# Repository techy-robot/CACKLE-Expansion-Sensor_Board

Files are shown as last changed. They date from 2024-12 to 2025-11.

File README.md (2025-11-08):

---
modified: 2025-11-07T22:07:23-07:00
---
# Sensor Board

> [!TIP]
> This board is part of a larger modular control board ecosystem, [CACKLE](https://github.com/techy-robot/CACKLE)

This is a connector breakout board for vertical mezzanine connectors on a hub. It has one Qwiic connector, two nanoSPI connectors, and header breakouts for the free pins, chip select pins, and the SPI pins. Essentially it breaks out every pin accessible via the mezzanine connector.

Note that this does not fit the hubs by default because it sticks into the hub chaining headers. You will need a Vertical Spacer, or use the [2 connector sensor breakout](../2%20connector%20Sensor%20Board/README.md) instead, which does fit.

Schematic PDF

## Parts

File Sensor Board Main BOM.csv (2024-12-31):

Id | Designator | Footprint | Quantity | Designation | Supplier and ref
1 | J1 | PinHeader_1x05_P1.27mm_Vertical | 1 | SPI
2 | J7 | JST_SH_SM04B-SRSS-TB_1x04-1MP_P1.00mm_Horizontal | 1 | JST SH
3 | J3 | PinHeader_1x03_P1.27mm_Vertical | 1 | free pins
4 | J2,J5 | fpc_7pin_0.3mm_connector Panasonic | 2 | 7 pin FPC 0.3mm Panasonic Y3b
5 | R2,R4 | R_0603_1608Metric | 2 | 10k
6 | J15 | TE_mezzanine_conn_3-2363962-0 | 1 | TE 3-2363962-0 Connector

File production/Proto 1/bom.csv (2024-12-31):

Designator | Footprint | Quantity | Value | LCSC Part #
J15 | TE_mezzanine_conn_3-2363962-0 | 1 | TE 3-2363962-0 Connector | C425104
J2, J5 | fpc_7pin_0.3mm_connector Panasonic | 2 | 7 pin FPC 0.3mm Panasonic Y3b
J7 | JST_SH_SM04B-SRSS-TB_1x04-1MP_P1.00mm_Horizontal | 1 | JST SH
R2, R4 | 0603 | 2 | 10k | C25804

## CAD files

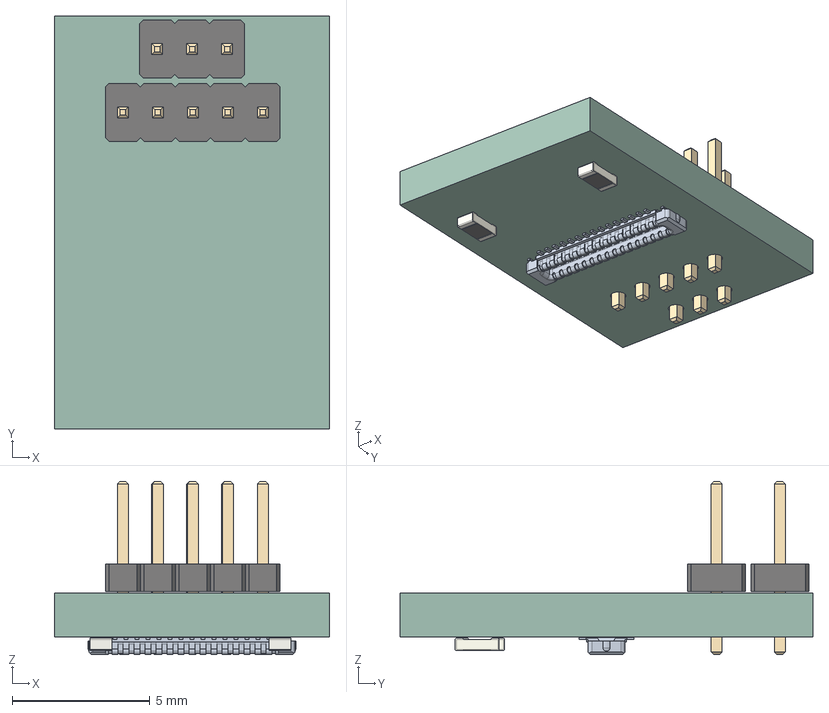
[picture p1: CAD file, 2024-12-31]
Sensor Board.step
10.0 x 15.0 x 6.30 mm
PinHeader_1x05_P127mm_Vertical
PinHeader_1x03_P127mm_Vertical
R_0603_1608Metric x 2
C-3-2363962-0
_autosave-Sensor Board_PCB

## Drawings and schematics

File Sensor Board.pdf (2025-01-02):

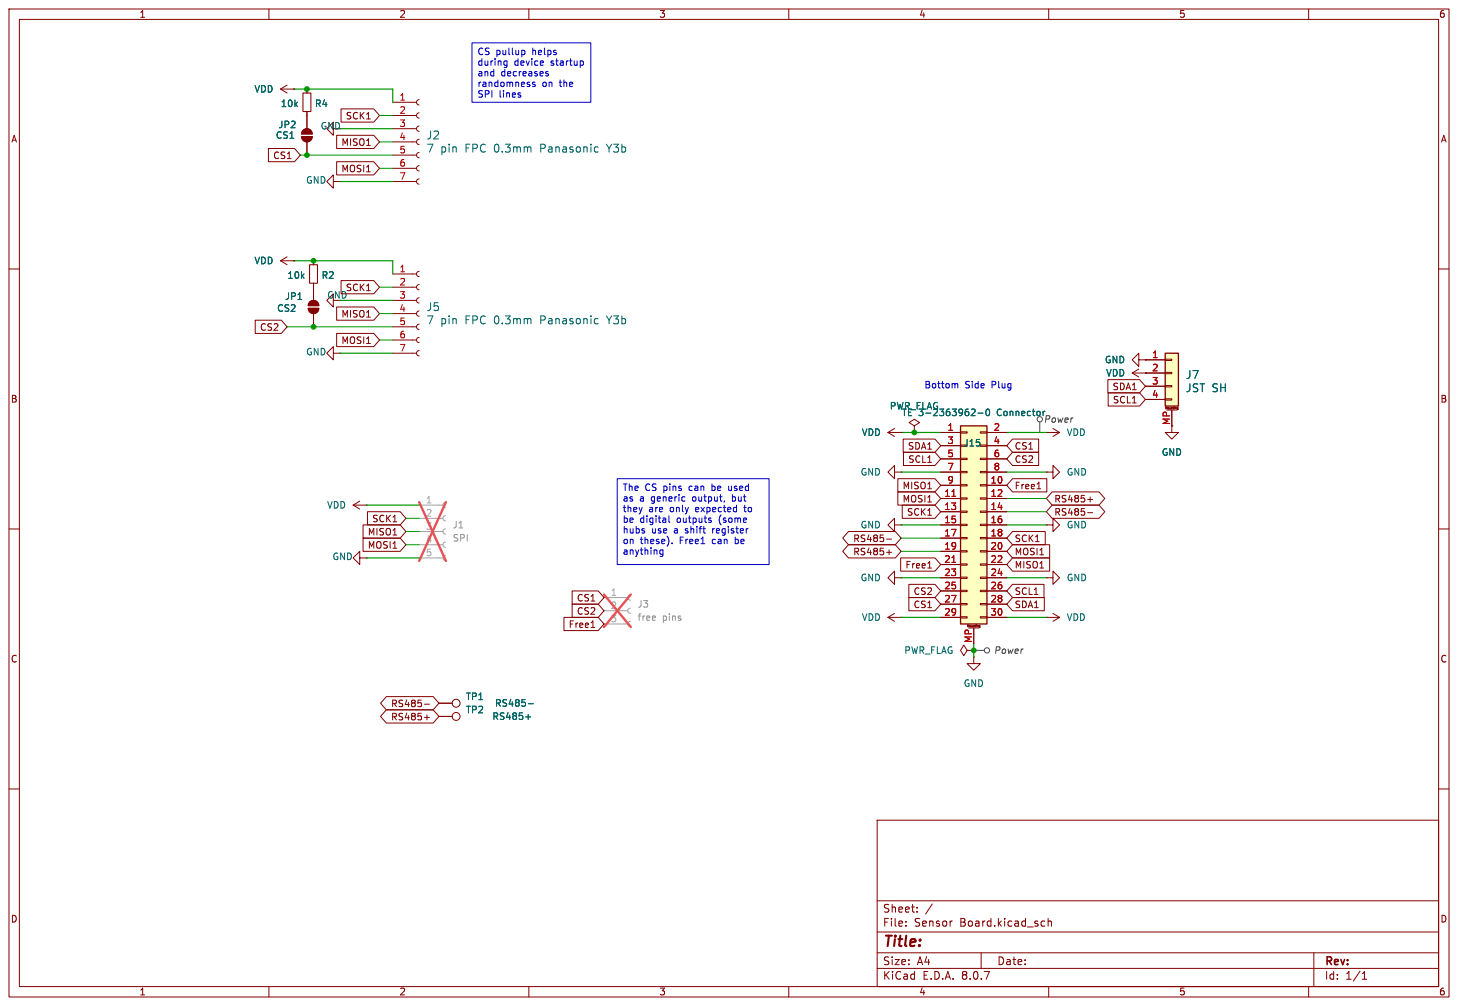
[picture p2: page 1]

JST SH 1234 MP GND
VDD

as a generic output, but
they are only expected to
hubs use a shift register on these). Free1 can be

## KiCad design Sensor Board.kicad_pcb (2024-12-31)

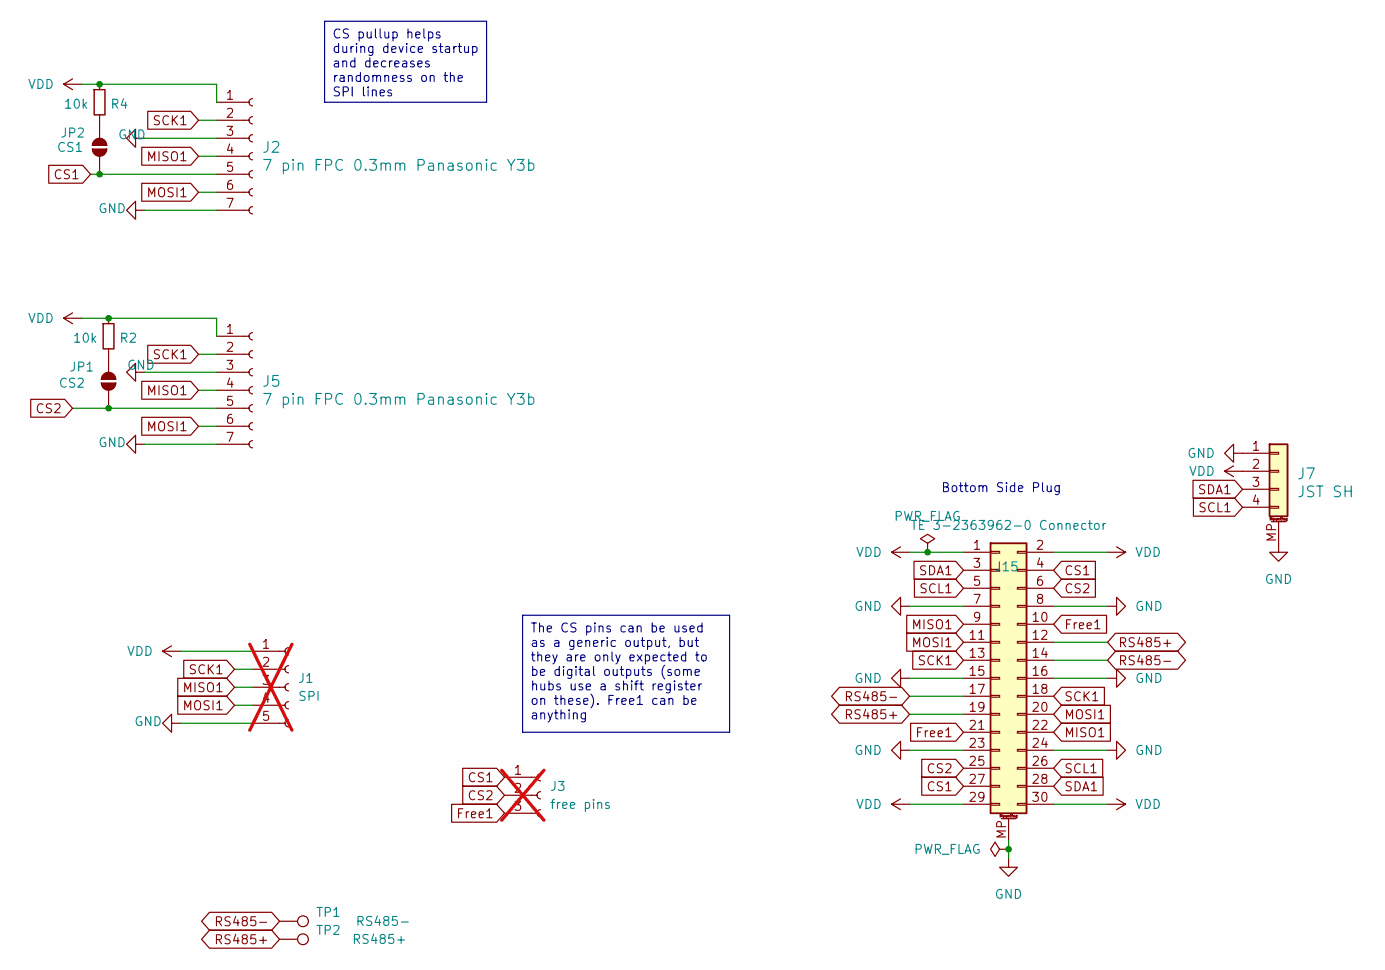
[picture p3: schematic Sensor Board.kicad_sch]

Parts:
J1: SPI; PinHeader_1x05_P1.27mm_Vertical; not fitted
J2, J5: 7 pin FPC 0.3mm Panasonic Y3b; fpc_7pin_0.3mm_connector Panasonic
J3: free pins; PinHeader_1x03_P1.27mm_Vertical; not fitted
J7: JST SH; JST_SH_SM04B-SRSS-TB_1x04-1MP_P1.00mm_Horizontal
J15: TE 3-2363962-0 Connector; TE_mezzanine_conn_3-2363962-0; LCSC C425104
JP1: CS2; SolderJumper-2_P1.3mm_Open_RoundedPad1.0x1.5mm
JP2: CS1; SolderJumper-2_P1.3mm_Open_RoundedPad1.0x1.5mm
R2, R4: 10k; R_0603_1608Metric; LCSC C25804
TP1: RS485-; TestPoint_Pad_D1.0mm
TP2: RS485+; TestPoint_Pad_D1.0mm

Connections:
CS1: J2.5, J3.1, J15.4, J15.27, JP2.1 (A)
CS2: J3.2, J5.5, J15.6, J15.25, JP1.1 (A)
Free1: J3.3, J15.10, J15.21
GND: J1.5, J2.3, J2.7, J5.3, J5.7, J7.1, J7.MP (MountPin), J15.7, J15.8, J15.15, J15.16, J15.23, J15.24, J15.MP (MountPin)
MISO1: J1.3, J2.4, J5.4, J15.9, J15.22
MOSI1: J1.4, J2.6, J5.6, J15.11, J15.20
unnamed: JP1.2 (B), R2.2
unnamed: JP2.2 (B), R4.2
RS485+: J15.12, J15.19, TP2.1
RS485-: J15.14, J15.17, TP1.1
SCK1: J1.2, J2.2, J5.2, J15.13, J15.18
SCL1: J7.4, J15.5, J15.26
SDA1: J7.3, J15.3, J15.28
VDD: J1.1, J2.1, J5.1, J7.2, J15.1, J15.2, J15.29, J15.30, R2.1, R4.1

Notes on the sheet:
CS pullup helps during device startup and decreases randomness on the SPI lines
The CS pins can be used as a generic output, but they are only expected to be digital outputs (some hubs use a shift register on these). Free1 can be anything
Bottom Side Plug

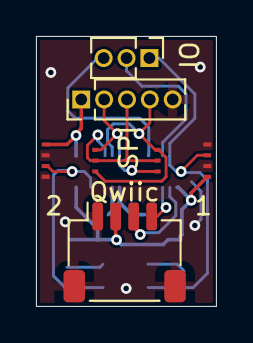
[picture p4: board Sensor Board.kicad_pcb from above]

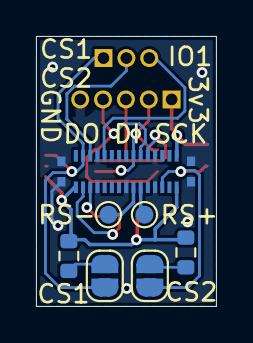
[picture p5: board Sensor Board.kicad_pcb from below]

Board: 2 copper layers, 10.0 x 15.0 mm, 12 parts (7 on the bottom side), 14 nets.

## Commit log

2024-12-31 Rearranged design files
    Instead of "Kicad" the main design folder is now named "Hardware" since I have gerbers and notes besides the kicad files. I have also put my designs in their proper categories.
    [Sensor Board Main BOM.csv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]
2025-01-02 Added schematic PDFs for all boards
2025-01-04 Added gerber zip files
2025-01-13 Changed link names for schematic embeds not displayin
    In Obsidian I can see the pdf embeds perfectly fine, but Github doesn't want to show embedded PDFs. I changed the link alias to "Schematic PDF" so people know what the link is when it doesn't display
2025-10-10 Moved all current production files to Proto 1.
    I haven't made a 2nd prototype yet
    [Sensor Board-B_Cu.gbl, Sensor Board-B_Mask.gbs, Sensor Board-B_Paste.gbp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]
